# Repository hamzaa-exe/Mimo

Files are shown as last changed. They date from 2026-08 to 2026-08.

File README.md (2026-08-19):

# Mimo

Mimo is a cute DIY desktop robot built around the Seeed Studio XIAO ESP32-S3. It combines a custom PCB, a 3D-printed enclosure, an OLED display, touch interaction, Wi-Fi, and audio to create a small interactive desktop companion.

Mimo normally displays cute animated eyes and different emotions. The user can interact with Mimo by touching the TTP223 sensor, which cycles through different modes such as time, weather, and the normal animation mode.

SCHEMATIC 1
SCHEMATIC 3
SChematic 2
PCB FINALLLLLLLLLLL
MIMO CASE FINAL 1
MIMO CASE FINAL

## Features

- Cute animated eyes and different emotions
- 2.42" SSD1309 OLED display
- TTP223 touch sensor for interaction
- Wi-Fi connectivity
- Online weather information
- Real-time clock display
- MAX98357A I2S audio amplifier
- Speaker for sounds and future voice playback
- Li-Po battery powered
- Physical ON/OFF switch
- Custom PCB designed in KiCad
- Custom 3D-printed enclosure designed in Fusion 360

## How It Works

Mimo starts in its normal animation mode, where the OLED continuously displays different eye expressions and emotions.

The TTP223 touch sensor is used to change between modes:

    First Touch  ->  Time
    Second Touch ->  Weather
    Third Touch  ->  Back to Animations

The ESP32-S3 connects to Wi-Fi and retrieves weather information from an online API. The MAX98357A amplifier is used to drive the speaker, allowing Mimo to produce sounds and eventually play recorded voice clips.

## Hardware

| Component | Purpose |
|---|---|
| XIAO ESP32-S3 | Main microcontroller |
| 2.42" SSD1309 OLED | Eyes, animations and information |
| TTP223 | Touch interaction |
| MAX98357A | I2S audio amplifier |
| Speaker | Sounds and voice |
| Li-Po Battery | Power source |
| Physical Switch | Power ON/OFF |
| Custom PCB | Main electronics board |

## Software

The firmware is being developed using Arduino IDE and C++.

Main libraries and technologies used:

- ESP32 Arduino Core
- U8g2
- ArduinoJson
- Wi-Fi
- HTTP requests
- I2S audio
- Online weather API

## Project Structure

    Mimo/
    ├── firmware/
    │   └── mimo.ino
    ├── pcb/
    │   └── KiCad/
    ├── case/
    │   └── Fusion360/
    ├── README.md
    └── LICENSE

## PCB

The Mimo PCB was designed from scratch in KiCad. It connects the XIAO ESP32-S3 with the OLED, touch sensor, audio amplifier, power system and other components.

The PCB is designed to fit inside the custom 3D-printed robot enclosure.

## Enclosure

The enclosure was designed in Fusion 360 specifically for Mimo's electronics. It includes mounting points for the PCB, openings for the OLED, USB connection, power switch and speaker, along with external horns to give Mimo its recognizable appearance.

## Future Plans

- Add more eye animations and emotions
- Add more touch interactions
- Improve weather animations
- Add battery status
- Add more sound effects
- Add sleep and wake animations
- Add additional interactive features

## Project Status

This project is being built as a complete DIY robot from the electronics and PCB design to the firmware and 3D-printed enclosure.

## License

This project is open source. See the LICENSE file for details.

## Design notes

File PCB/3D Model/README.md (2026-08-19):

Folder contains all 3D Models in PCB design

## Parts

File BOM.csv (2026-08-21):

# | Component | Qty | Total (USD) | Purchase Link
1 | XIAO ESP32-S3 | 1 | $7 | www.aliexpress.com
2 | 2.42" SSD1309 OLED 128x64 I2C | 1 | $5.12 | www.aliexpress.com
3 | TTP223 Capacitive Touch Sensor | 1 | $3.67 | www.aliexpress.com
4 | MAX98357A I2S Audio Amplifier | 1 | $3.09 | www.aliexpress.com
5 | 3W 4-ohm Speaker | 1 | $1.37 | www.aliexpress.com
6 | 3.7V Li-Po Battery | 1 | $2.00 | www.aliexpress.com
7 | Slide ON/OFF Switch | 1 | $1.50 | www.aliexpress.com
8 | Custom Mimo PCB | 1 | $2 | https://jlcpcb.com
9 | PCB Shipping | 1 | $13 | https://jlcpcb.com
10 | 3D-Printed Mimo Enclosure | 1 | $10 | Hackclub Printing Legion
11 | M2 Screws + Nuts/Standoffs | 1 set | $5 | www.aliexpress.com
13 | 2.54mm Pin Headers | 1 pack | $4 | www.aliexpress.com
14 | 4x4 Inch Fur Fabric Piece | 1 | $5 | www.aliexpress.com
15 | Aliexpress Shipping | 1 | $35 | www.aliexpress.com
16 | 4.7K 0805 SMD resistor | 2 | $1.81 | www.aliexpress.com
17 | 100nF 0805 SMD ceramic capacitor | 2 | $0.61 | www.aliexpress.com
18 | 100uF SMD electrolytic capacitor 6.3V | 1 | $2.19 | www.alixpress.com
 |  | TOTAL: | $100

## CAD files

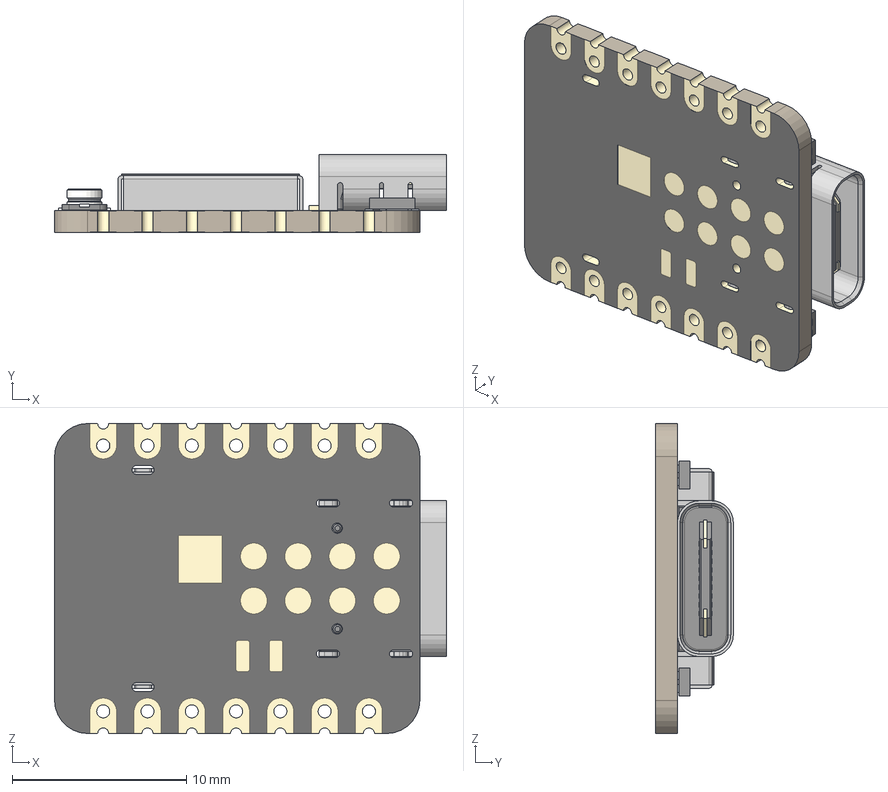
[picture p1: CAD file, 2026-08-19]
PCB/3D Model/XIAO-ESP32S3 v3.step
22.5 x 4.46 x 17.8 mm
BOSS-EXTRUDE14_8_
BOSS-EXTRUDE7_4_
BOSS-EXTRUDE7_3_
BOSS-EXTRUDE14_4_
BOSS-EXTRUDE14_2_
BOSS-EXTRUDE14_11_
BOSS-EXTRUDE7_7_
BOSS-EXTRUDE14_9_
BOSS-EXTRUDE14_3_
BOSS-EXTRUDE14_7_
MIRROR2
BOSS-EXTRUDE14_5_
BOSS-EXTRUDE14_12_
BOSS-EXTRUDE7_8_
BOSS-EXTRUDE7_1_
BOSS-EXTRUDE14_10_
BOSS-EXTRUDE7_9_
BOSS-EXTRUDE14_6_
BOSS-EXTRUDE14_1_
BOSS-EXTRUDE7_6_
BOSS-EXTRUDE7_2_
CUT-EXTRUDE5
BOSS-EXTRUDE7_5_
Shield
Pins x 2
U.FL-R-SMT-1_10_ v1

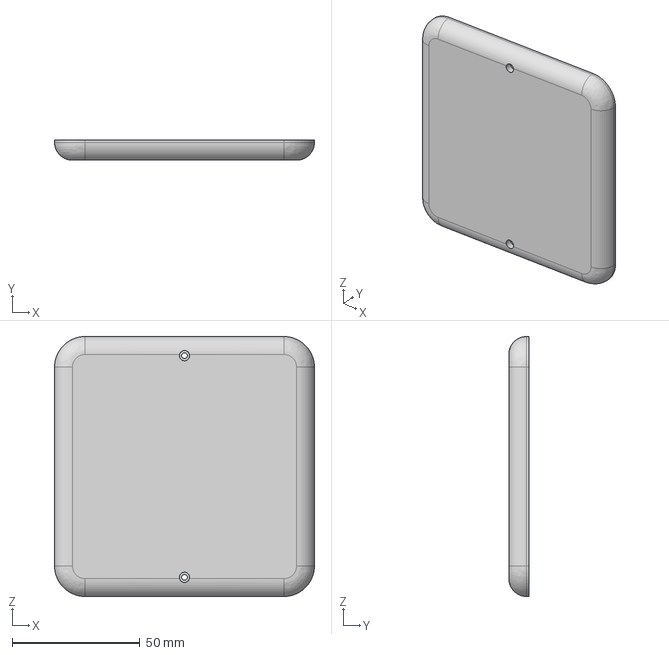
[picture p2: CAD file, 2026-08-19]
Production/Mimo Top simple.step
101.6 x 8.00 x 101.6 mm

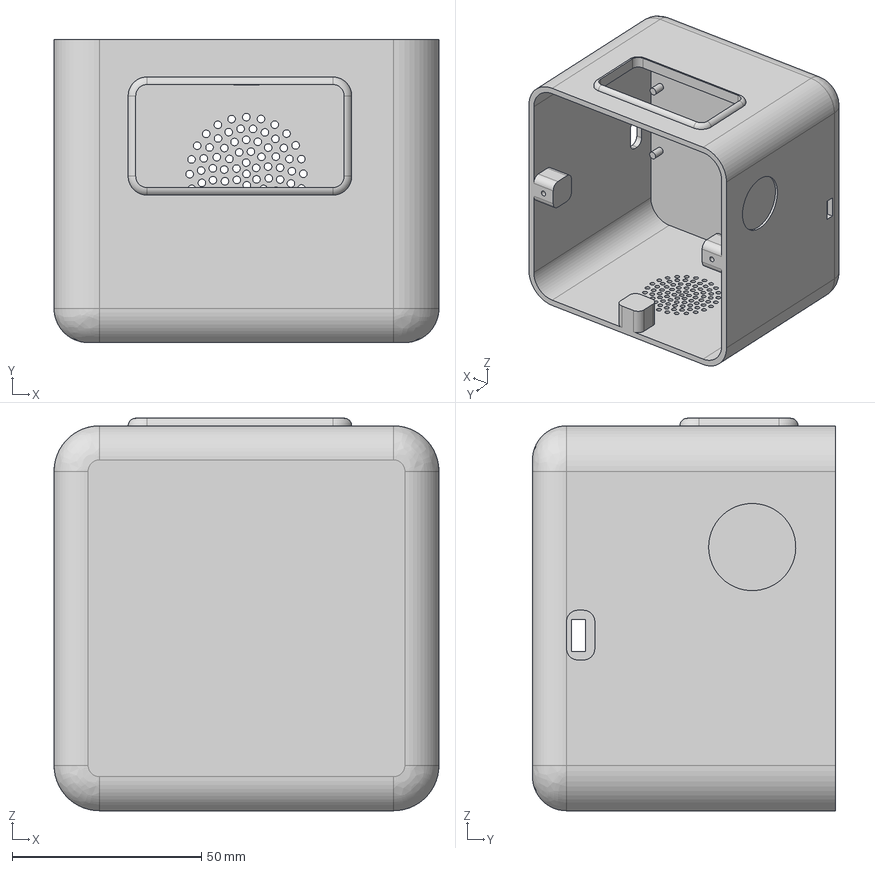
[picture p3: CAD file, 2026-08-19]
Production/Mimo Base simple.step
101.6 x 80.0 x 103.6 mm

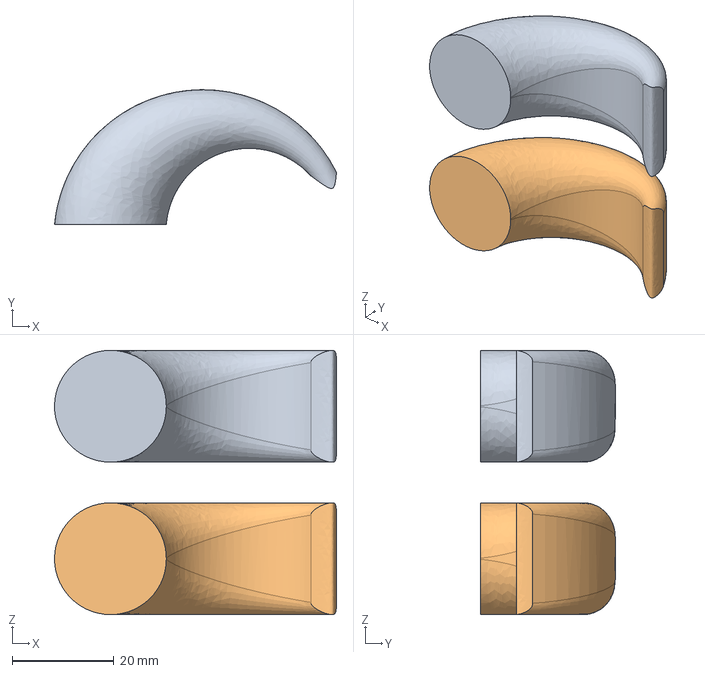
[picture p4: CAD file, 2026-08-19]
Production/Mimo Horns simple.step
55.5 x 26.5 x 52.0 mm

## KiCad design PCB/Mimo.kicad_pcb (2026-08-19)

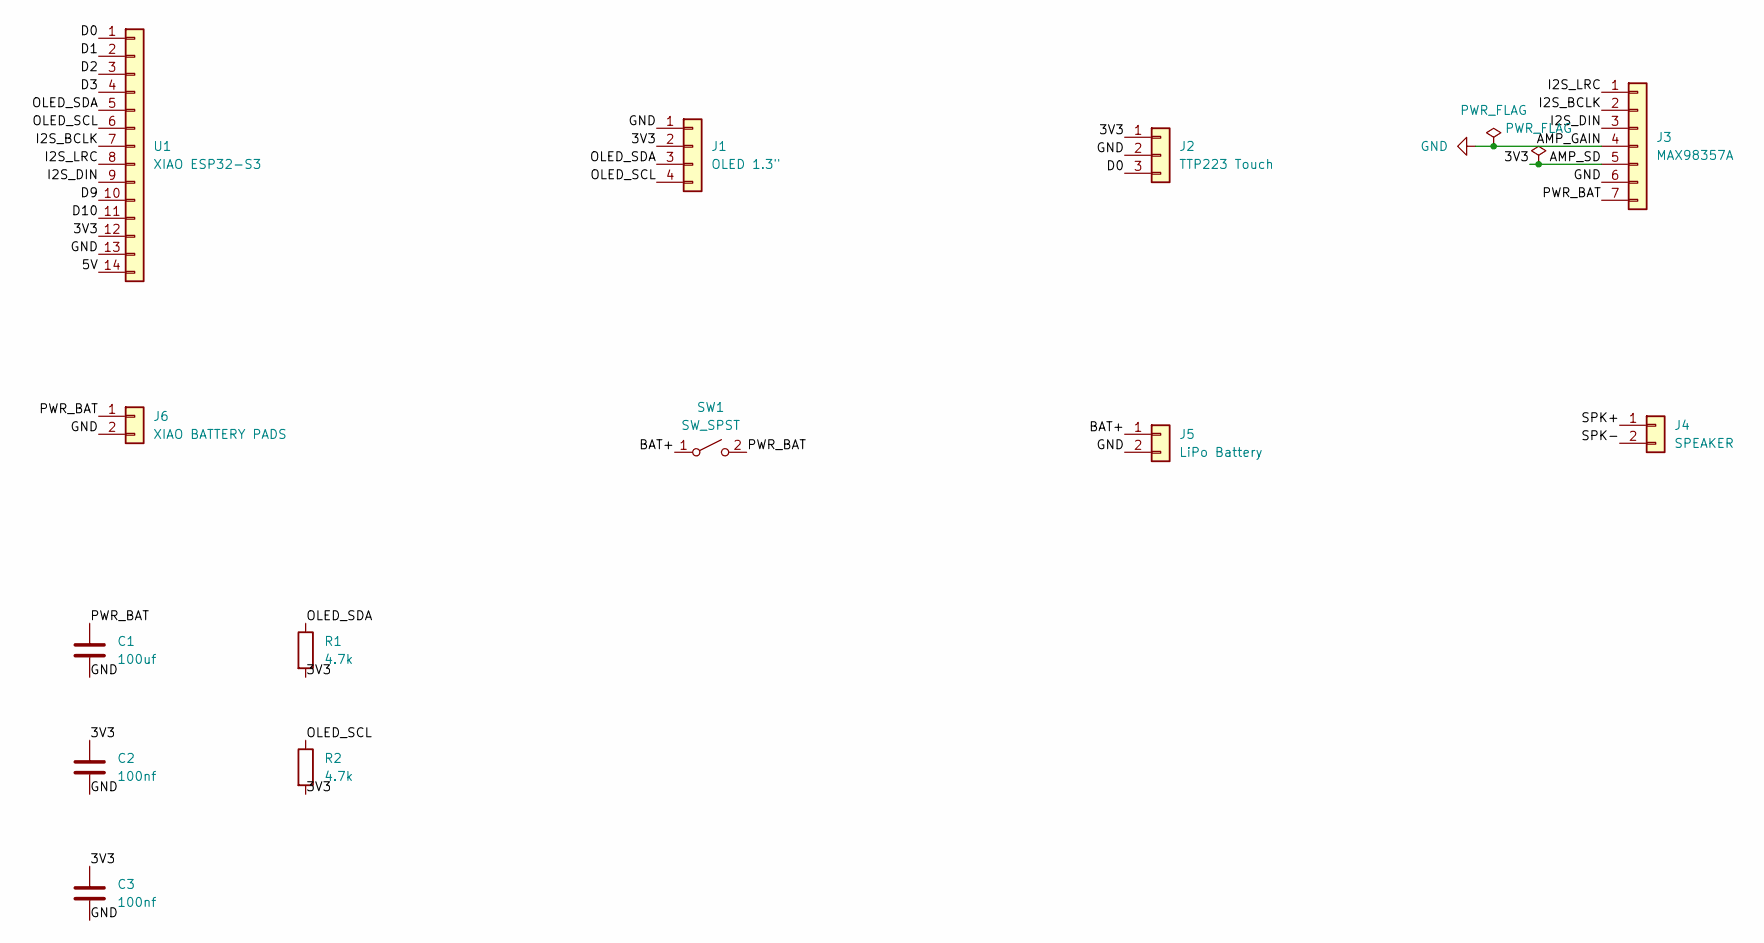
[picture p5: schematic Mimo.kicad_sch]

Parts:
C1: 100uf; CP_Radial_D6.3mm_P2.50mm
C2, C3: 100nf; C_0805_2012Metric
J1: OLED 1.3"; JST_PH_B4B-PH-K_1x04_P2.00mm_Vertical
J2: TTP223 Touch; JST_PH_B3B-PH-K_1x03_P2.00mm_Vertical
J3: MAX98357A; PinHeader_1x07_P2.54mm_Vertical
J4: SPEAKER; JST_PH_B2B-PH-K_1x02_P2.00mm_Vertical
J5: LiPo Battery; JST_PH_B2B-PH-K_1x02_P2.00mm_Vertical
J6: XIAO BATTERY PADS; JST_PH_B2B-PH-K_1x02_P2.00mm_Vertical
R1, R2: 4.7k; R_0805_2012Metric
SW1: SW_SPST; SW_SPDT_PCM12
U1: XIAO ESP32-S3; XIAO-ESP32-S3-DIP

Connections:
/3V3: C2.1, C3.1, J1.2, J2.1, J3.5, R1.2, R2.2, U1.12
/5V: U1.14
/BAT+: J5.1, SW1.1 (A)
/D0: J2.3, U1.1
/D1: U1.2
/D2: U1.3
/D3: U1.4
/D9: U1.10
/D10: U1.11
/I2S_BCLK: J3.2, U1.7
/I2S_DIN: J3.3, U1.9
/I2S_LRC: J3.1, U1.8
/OLED_SCL: J1.4, R2.1, U1.6
/OLED_SDA: J1.3, R1.1, U1.5
/PWR_BAT: C1.1, J3.7, J6.1, SW1.2 (B)
/SPK+: J4.1
/SPK-: J4.2
GND: C1.2, C2.2, C3.2, J1.1, J2.2, J3.4, J3.6, J5.2, J6.2, U1.13

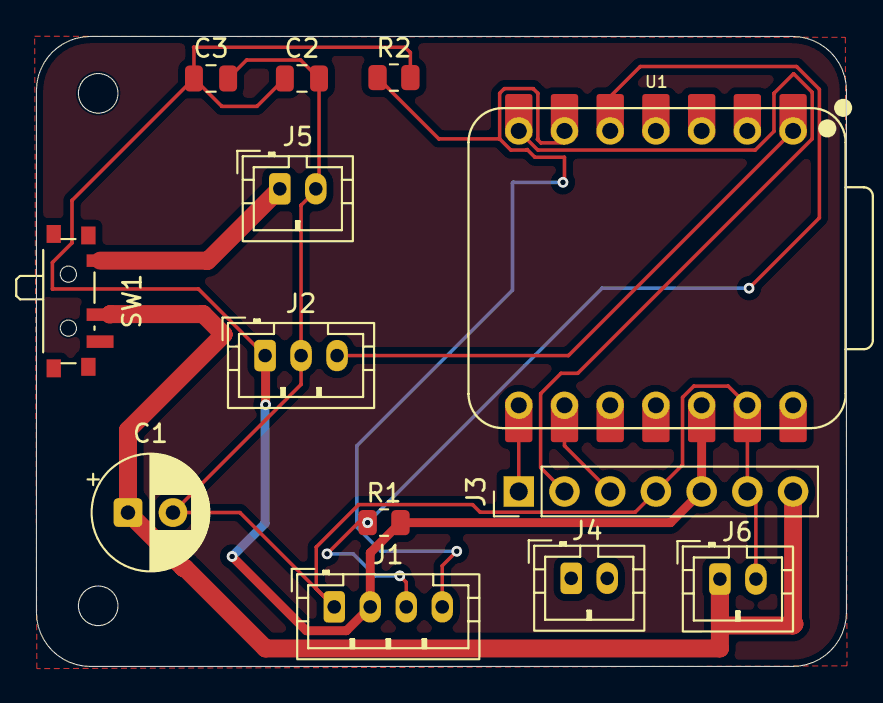
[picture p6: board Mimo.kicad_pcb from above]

Board: 2 copper layers, 45.0 x 35.0 mm, 13 parts (0 on the bottom side), 10 nets.

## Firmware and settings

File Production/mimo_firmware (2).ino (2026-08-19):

#include <Arduino.h>
#include <Wire.h>
#include <WiFi.h>
#include <HTTPClient.h>
#include <ArduinoJson.h>
#include <U8g2lib.h>
#include "driver/i2s_std.h"


// ========================================================
// USER SETTINGS
// ========================================================

// ---------- WiFi ----------
const char* WIFI_SSID     = "Test";
const char* WIFI_PASSWORD = "12345678";

// ---------- Weather ----------
const char* CITY = "Rawalpindi";
const char* COUNTRY_CODE = "PK";

// Open-Meteo does not require an API key.
// The program obtains latitude/longitude from the
// Open-Meteo geocoding service.

// ---------- Your location ----------
float LATITUDE  = 33.5651;
float LONGITUDE = 73.0169;


// ========================================================
// PIN DEFINITIONS
// ========================================================

// OLED
#define OLED_SDA_PIN 5     // XIAO D4
#define OLED_SCL_PIN 6     // XIAO D5

// Touch
#define TOUCH_PIN 1        // XIAO D0 = GPIO1

// MAX98357A I2S
// Change these three if your physical wiring is different.
#define I2S_BCLK_PIN 43    // XIAO D6
#define I2S_LRC_PIN  44    // XIAO D7
#define I2S_DIN_PIN   7    // XIAO D8


// ========================================================
// OLED
// ========================================================

// SSD1309 128x64 I2C
U8G2_SSD1309_128X64_NONAME0_F_HW_I2C oled(
  U8G2_R0,
  U8X8_PIN_NONE
);


// ========================================================
// I2S
// ========================================================

i2s_chan_handle_t tx_handle;


// ========================================================
// MIMO STATES
// ========================================================

enum RobotMode
{
  MODE_ANIMATION,
  MODE_TIME,
  MODE_WEATHER
};

RobotMode mode = MODE_ANIMATION;


// ========================================================
// TIMING
// ========================================================

unsigned long lastTouch = 0;
unsigned long screenStart = 0;
unsigned long lastAnimation = 0;

const unsigned long TOUCH_DELAY = 500;
const unsigned long INFO_TIMEOUT = 8000;


// ========================================================
// ANIMATION
// ========================================================

int animationFrame = 0;

enum Emotion
{
  HAPPY,
  NORMAL,
  LOVE,
  SLEEPY,
  SURPRISED,
  ANGRY
};

Emotion currentEmotion = NORMAL;


// ========================================================
// WEATHER DATA
// ========================================================

String weatherText = "Loading...";
float temperature = 0;

bool weatherAvailable = false;


// ========================================================
// I2S INITIALIZATION
// ========================================================

void setupI2S()
{
  i2s_chan_config_t chan_cfg =
    I2S_CHANNEL_DEFAULT_CONFIG(
      I2S_NUM_AUTO,
      I2S_ROLE_MASTER
    );

  i2s_new_channel(
    &chan_cfg,
    &tx_handle,
    NULL
  );

  i2s_std_config_t std_cfg = {

    .clk_cfg =
      I2S_STD_CLK_DEFAULT_CONFIG(22050),

    .slot_cfg =
      I2S_STD_MSB_SLOT_DEFAULT_CONFIG(
        I2S_DATA_BIT_WIDTH_16BIT,
        I2S_SLOT_MODE_MONO
      ),

    .gpio_cfg = {
      .mclk = I2S_GPIO_UNUSED,
      .bclk = (gpio_num_t)I2S_BCLK_PIN,
      .ws   = (gpio_num_t)I2S_LRC_PIN,
      .dout = (gpio_num_t)I2S_DIN_PIN,
      .din  = I2S_GPIO_UNUSED
    }
  };

  i2s_channel_init_std_mode(
    tx_handle,
    &std_cfg
  );

  i2s_channel_enable(tx_handle);
}


// ========================================================
// PLAY SIMPLE CUTE SOUND
// ========================================================

void playTone(
  float frequency,
  int duration,
  float volume = 0.15
)
{
  const int sampleRate = 22050;

  int samples =
    sampleRate * duration / 1000;

  int16_t* buffer =
    (int16_t*)malloc(samples * sizeof(int16_t));

  if (!buffer)
    return;

  for (int i = 0; i < samples; i++)
  {
    float t =
      (float)i / sampleRate;

    float wave =
      sin(2.0 * PI * frequency * t);

    buffer[i] =
      (int16_t)(
        wave *
        32767 *
        volume
      );
  }

  size_t bytesWritten;

  i2s_channel_write(
    tx_handle,
    buffer,
    samples * sizeof(int16_t),
    &bytesWritten,
    portMAX_DELAY
  );

  free(buffer);
}


// ========================================================
// MIMO VOICE
// ========================================================

void mimoHello()
{
  playTone(700, 100);
  playTone(900, 120);
  playTone(1200, 180);
}

void mimoHappy()
{
  playTone(900, 80);
  playTone(1200, 100);
  playTone(1500, 180);
}

void mimoTouchSound()
{
  playTone(1000, 70);
  playTone(1400, 100);
}

void mimoWeatherSound()
{
  playTone(700, 100);
  playTone(850, 100);
  playTone(1100, 180);
}


// ========================================================
// DRAW EYES
// ========================================================

void drawNormalEyes()
{
  oled.clearBuffer();

  // left eye
  oled.drawRBox(
    25,
    20,
    28,
    25,
    7
  );

  // right eye
  oled.drawRBox(
    75,
    20,
    28,
    25,
    7
  );

  oled.sendBuffer();
}


// ========================================================
// HAPPY EYES
// ========================================================

void drawHappyEyes()
{
  oled.clearBuffer();

  // left happy eye
  oled.drawDisc(
    39,
    32,
    15
  );

  // right happy eye
  oled.drawDisc(
    89,
    32,
    15
  );

  // black lower cuts to make smile-like eyes
  oled.setDrawColor(0);

  oled.drawBox(
    22,
    32,
    34,
    20
  );

  oled.drawBox(
    72,
    32,
    34,
    20
  );

  oled.setDrawColor(1);

  oled.sendBuffer();
}


// ========================================================
// LOVE EYES
// ========================================================

void drawLoveEyes()
{
  oled.clearBuffer();

  // left heart
  oled.drawDisc(32, 29, 8);
  oled.drawDisc(45, 29, 8);
  oled.drawTriangle(
    24, 33,
    53, 33,
    38, 48
  );

  // right heart
  oled.drawDisc(78, 29, 8);
  oled.drawDisc(91, 29, 8);
  oled.drawTriangle(
    70, 33,
    99, 33,
    85, 48
  );

  oled.sendBuffer();
}


// ========================================================
// SURPRISED
// ========================================================

void drawSurprised()
{
  oled.clearBuffer();

  oled.drawCircle(
    39,
    32,
    14
  );

  oled.drawCircle(
    89,
    32,
    14
  );

  oled.sendBuffer();
}


// ========================================================
// SLEEPY
// ========================================================

void drawSleepy()
{
  oled.clearBuffer();

  oled.drawLine(
    22, 34,
    54, 34
  );

  oled.drawLine(
    74, 34,
    106, 34
  );

  oled.sendBuffer();
}


// ========================================================
// ANGRY
// ========================================================

void drawAngry()
{
  oled.clearBuffer();

  oled.drawLine(
    22, 22,
    54, 30
  );

  oled.drawLine(
    74, 30,
    106, 22
  );

  oled.drawRBox(
    27,
    30,
    25,
    15,
    4
  );

  oled.drawRBox(
    76,
    30,
    25,
    15,
    4
  );

  oled.sendBuffer();
}


// ========================================================
// RANDOM EMOTION
// ========================================================

void randomEmotion()
{
  int e = random(0, 5);

  switch (e)
  {
    case 0:
      currentEmotion = NORMAL;
      break;

    case 1:
      currentEmotion = HAPPY;
      break;

    case 2:
      currentEmotion = LOVE;
      break;

    case 3:
      currentEmotion = SLEEPY;
      break;

    case 4:
      currentEmotion = SURPRISED;
      break;
  }
}


// ========================================================
// ANIMATION LOOP
// ========================================================

void animateMimo()
{
  if (
    millis() -
    lastAnimation <
    1200
  )
    return;

  lastAnimation = millis();

  animationFrame++;

  if (animationFrame % 5 == 0)
  {
    randomEmotion();
  }

  switch (currentEmotion)
  {
    case NORMAL:
      drawNormalEyes();
      break;

    case HAPPY:
      drawHappyEyes();
      break;

    case LOVE:
      drawLoveEyes();
      break;

    case SLEEPY:
      drawSleepy();
      break;

    case SURPRISED:
      drawSurprised();
      break;

    case ANGRY:
      drawAngry();
      break;
  }
}


// ========================================================
// SHOW TIME
// ========================================================

void showTime()
{
  struct tm timeinfo;

  if (!getLocalTime(&timeinfo))
  {
    oled.clearBuffer();

    oled.setFont(
      u8g2_font_6x12_tf
    );

    oled.drawStr(
      20,
      30,
      "No time :("
    );

    oled.sendBuffer();

    return;
  }

  char timeString[20];

  strftime(
    timeString,
    sizeof(timeString),
    "%H:%M",
    &timeinfo
  );

  char dateString[30];

  strftime(
    dateString,
    sizeof(dateString),
    "%d/%m/%Y",
    &timeinfo
  );

  oled.clearBuffer();

  oled.setFont(
    u8g2_font_6x12_tf
  );

  oled.drawStr(
    48,
    12,
    "TIME"
  );

  oled.setFont(
    u8g2_font_logisoso24_tf
  );

  oled.drawStr(
    18,
    43,
    timeString
  );

  oled.setFont(
    u8g2_font_6x12_tf
  );

  oled.drawStr(
    39,
    59,
    dateString
  );

  oled.sendBuffer();
}


// ========================================================
// WEATHER
// ========================================================

void getWeather()
{
  if (WiFi.status() != WL_CONNECTED)
  {
    weatherAvailable = false;
    return;
  }

  HTTPClient http;

  String url =
    "https://api.open-meteo.com/v1/forecast?"
    "latitude=" +
    String(LATITUDE, 4) +
    "&longitude=" +
    String(LONGITUDE, 4) +
    "&current=temperature_2m,weather_code"
    "&timezone=auto";

  http.begin(url);

  int httpCode =
    http.GET();

  if (httpCode == 200)
  {
    String payload =
      http.getString();

    JsonDocument doc;

    DeserializationError error =
      deserializeJson(
        doc,
        payload
      );

    if (!error)
    {
      temperature =
        doc["current"]
           ["temperature_2m"];

      int weatherCode =
        doc["current"]
           ["weather_code"];

      weatherText =
        weatherCodeToText(
          weatherCode
        );

      weatherAvailable = true;
    }
  }

  http.end();
}


// ========================================================
// WEATHER CODE CONVERSION
// ========================================================

String weatherCodeToText(
  int code
)
{
  if (code == 0)
    return "Sunny";

  if (code <= 3)
    return "Cloudy";

  if (code <= 48)
    return "Foggy";

  if (code <= 67)
    return "Rain";

  if (code <= 77)
    return "Snow";

  if (code <= 82)
    return "Showers";

  if (code <= 86)
    return "Snow";

  return "Storm";
}


// ========================================================
// SHOW WEATHER
// ========================================================

void showWeather()
{
  if (!weatherAvailable)
  {
    oled.clearBuffer();

    oled.setFont(
      u8g2_font_6x12_tf
    );

    oled.drawStr(
      20,
      25,
      "Weather unavailable"
    );

    oled.drawStr(
      28,
      45,
      "Check WiFi :("
    );

    oled.sendBuffer();

    return;
  }

  oled.clearBuffer();

  oled.setFont(
    u8g2_font_6x12_tf
  );

  oled.drawStr(
    42,
    12,
    "WEATHER"
  );

  oled.setFont(
    u8g2_font_logisoso24_tf
  );

  String temp =
    String(
      temperature,
      1
    ) +
    "C";

  oled.drawStr(
    25,
    43,
    temp.c_str()
  );

  oled.setFont(
    u8g2_font_6x12_tf
  );

  oled.drawStr(
    42,
    59,
    weatherText.c_str()
  );

  oled.sendBuffer();
}


// ========================================================
// WIFI
// ========================================================

void connectWiFi()
{
  oled.clearBuffer();

  oled.setFont(
    u8g2_font_6x12_tf
  );

  oled.drawStr(
    25,
    30,
    "Connecting WiFi..."
  );

  oled.sendBuffer();

  WiFi.begin(
    WIFI_SSID,
    WIFI_PASSWORD
  );

  int attempts = 0;

  while (
    WiFi.status() != WL_CONNECTED &&
    attempts < 30
  )
  {
    delay(500);
    attempts++;
  }

  oled.clearBuffer();

  if (WiFi.status() == WL_CONNECTED)
  {
    oled.drawStr(
      32,
      30,
      "WiFi OK!"
    );

    oled.sendBuffer();

    delay(800);
  }
  else
  {
    oled.drawStr(
      25,
      30,
      "WiFi failed :("
    );

    oled.sendBuffer();

    delay(800);
  }
}


// ========================================================
// NTP TIME
// ========================================================

void setupTime()
{
  // Pakistan UTC+5
  configTime(
    5 * 3600,
    0,
    "pool.ntp.org",
    "time.nist.gov"
  );
}


// ========================================================
// TOUCH
// ========================================================

void touchPressed()
{
  if (
    millis() -
    lastTouch <
    TOUCH_DELAY
  )
    return;

  lastTouch = millis();

  mimoTouchSound();

  if (mode == MODE_ANIMATION)
  {
    mode = MODE_TIME;

    screenStart =
      millis();

    showTime();
  }

  else if (mode == MODE_TIME)
  {
    mode = MODE_WEATHER;

    screenStart =
      millis();

    getWeather();

    mimoWeatherSound();

    showWeather();
  }

  else
  {
    mode = MODE_ANIMATION;

    screenStart =
      millis();

    mimoHappy();

    drawHappyEyes();
  }
}


// ========================================================
// SETUP
// ========================================================

void setup()
{
  Serial.begin(115200);

  randomSeed(
    analogRead(0)
  );

  // Touch
  pinMode(
    TOUCH_PIN,
    INPUT
  );

  // OLED
  Wire.begin(
    OLED_SDA_PIN,
    OLED_SCL_PIN
  );

  oled.begin();

  oled.clearBuffer();

  oled.setFont(
    u8g2_font_6x12_tf
  );

  oled.drawStr(
    45,
    30,
    "MIMO"
  );

  oled.drawStr(
    32,
    48,
    "Starting..."
  );

  oled.sendBuffer();

  // Audio
  setupI2S();

  mimoHello();

  // WiFi
  connectWiFi();

  // Time
  setupTime();

  // Weather
  getWeather();

  // Start animation
  mode =
    MODE_ANIMATION;

  screenStart =
    millis();

  drawHappyEyes();

  delay(1000);
}


// ========================================================
// MAIN LOOP
// ========================================================

void loop()
{
  // ------------------------------------------------------
  // TOUCH
  // ------------------------------------------------------

  if (
    digitalRead(TOUCH_PIN)
    == HIGH
  )
  {
    touchPressed();

    // Wait until finger is removed
    while (
      digitalRead(TOUCH_PIN)
      == HIGH
    )
    {
      delay(10);
    }
  }


  // ------------------------------------------------------
  // AUTOMATIC RETURN TO ANIMATION
  // ------------------------------------------------------

  if (
    mode != MODE_ANIMATION &&
    millis() -
    screenStart >
    INFO_TIMEOUT
  )
  {
    mode =
      MODE_ANIMATION;

    drawNormalEyes();
  }


  // ------------------------------------------------------
  // ANIMATION
  // ------------------------------------------------------

  if (
    mode ==
    MODE_ANIMATION
  )
  {
    animateMimo();
  }


  // ------------------------------------------------------
  // UPDATE TIME SCREEN
  // ------------------------------------------------------

  if (
    mode ==
    MODE_TIME
  )
  {
    static unsigned long lastClock =
      0;

    if (
      millis() -
      lastClock >
      1000
    )
    {
      lastClock =
        millis();

      showTime();
    }
  }


  delay(10);
}

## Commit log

2026-08-19 CAD folder
2026-08-19 Mimo PCB design files
2026-08-19 Create BOM.md file
2026-08-19 Added mimo cad production files
    [Mimo Base simple.step, Mimo Horns simple.step, Mimo Top simple.step]
2026-08-19 Update and rename BOM.md to BOM.csv
    [BOM.csv]
2026-08-25 Adjust prices for Mimo Enclosure and total cost
    Updated the price of the 3D-Printed Mimo Enclosure and adjusted the total cost accordingly.
2026-11-10 Revise component prices and links in BOM.csv
    Updated purchase links and prices for various components in BOM.csv.
2026-11-10 Update BOM.csv total cost from $95 to $105
2026-11-10 Adjust total cost in BOM.csv to reflect new pricing
2026-11-13 Update BOM.csv with new prices and total
